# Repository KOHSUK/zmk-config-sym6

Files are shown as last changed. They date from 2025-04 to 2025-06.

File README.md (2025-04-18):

# Symphonie Nr.6 in F-Dur, op. 68, Pastorale

## License & Attribution

The PMW3610 portion of this PCB design is based on “pmw3610_breakout_for_roBa”  
originally created by kumamuk‑git (https://github.com/kumamuk‑git/roBa/tree/main/pcb/pmw3610_breakout_for_roBa).
© kumamuk‑git. Licensed under GNU General Public License v3.0 (GPL‑3.0).

This modified design (files under `pcb`) is also distributed under GPL‑3.0.  
Corresponding source (KiCad project) is available at:  
https://github.com/KOHSUK/zmk-config-sym6/tree/main/pcb/assemble_right/

See LICENSE (GPL‑3.0) for full terms.

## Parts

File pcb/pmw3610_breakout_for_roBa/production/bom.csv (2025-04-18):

Designator | Footprint | Quantity | Value | LCSC Part #
C1 | 0603 | 1 | 1u | C14663
C2 | 0603 | 1 | 1u | C15849
C3, C8 | 0603 | 2 | 100n | C19666
C4 | 0603 | 1 | 10n | C19666
C5 | 0603 | 1 | 100n (X7R) | C19666
C6 | 0603 | 1 | 10u (X7R) | C19666
C7 | 0603 | 1 | 10n (X7R) | C19666
C9 | 0603 | 1 | 3.3u/25V | C19666
J1 | pmw3610_connector_b | 1 | Conn_01x08
R1 | 0603 | 1 | 2M
U1 | SOT-23 | 1 | MCP1700T-1802E/TT
U2 | PMW3610DM-SUDU 16Pin | 1 | PMW3610

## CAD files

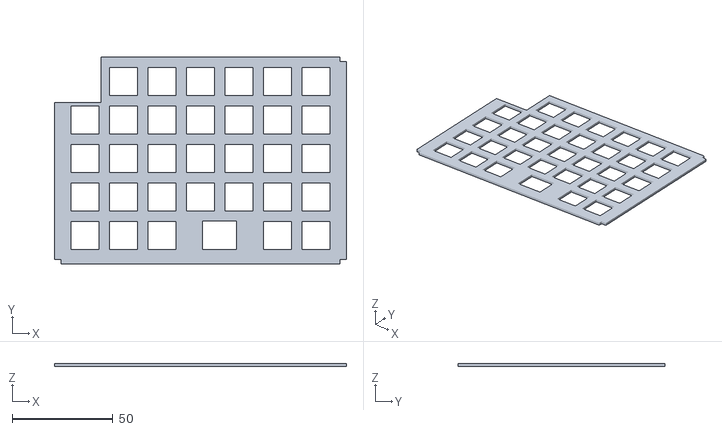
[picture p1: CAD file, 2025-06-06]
models/left_v3/top-plate-l.stl
144.7 x 102.7 x 1.60

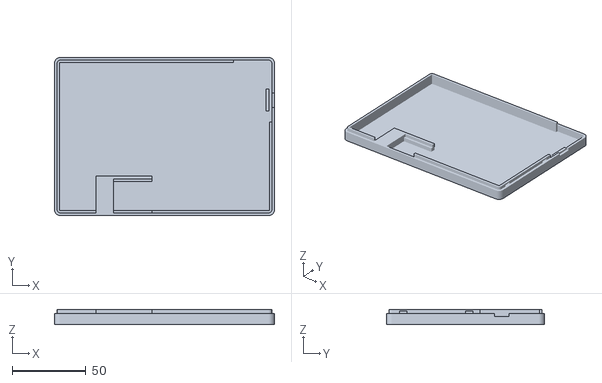
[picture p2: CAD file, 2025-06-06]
models/right_v3/bottom-case-r.stl
149.3 x 107.3 x 9.90

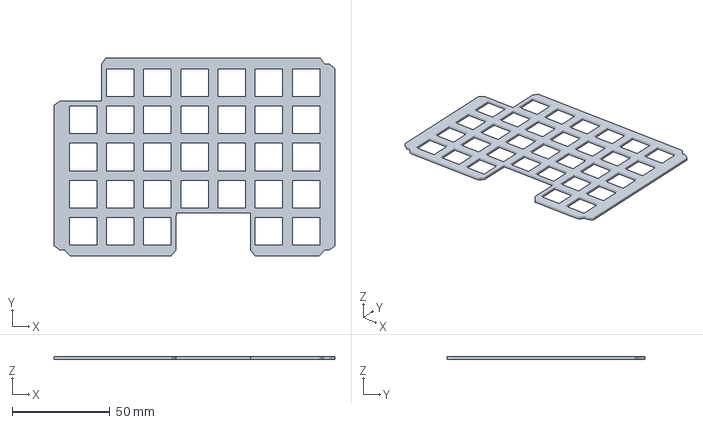
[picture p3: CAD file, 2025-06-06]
models/top_left/top-left.3mf
144.0 x 101.2 x 1.60 mm

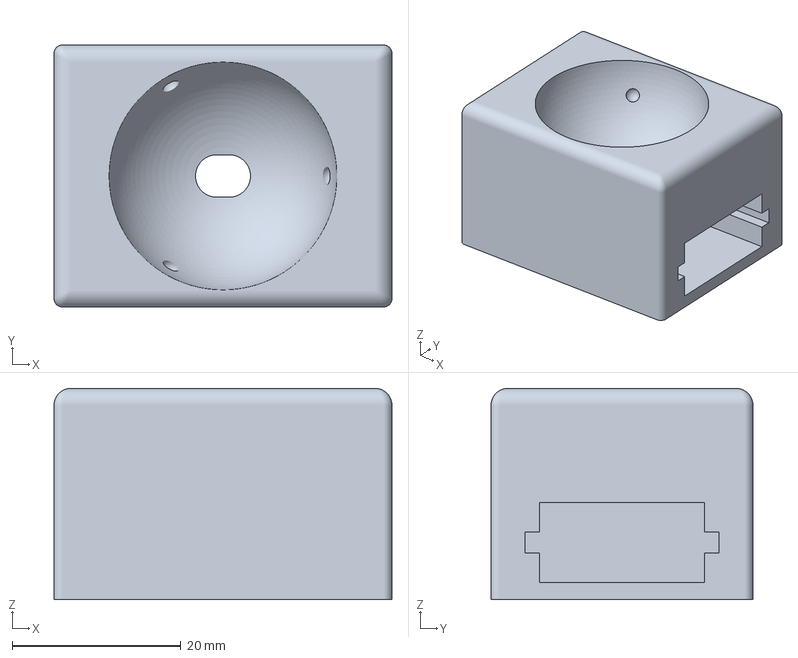
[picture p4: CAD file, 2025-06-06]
models/trackball/trackball-case-v1.3mf
40.0 x 31.0 x 25.0 mm

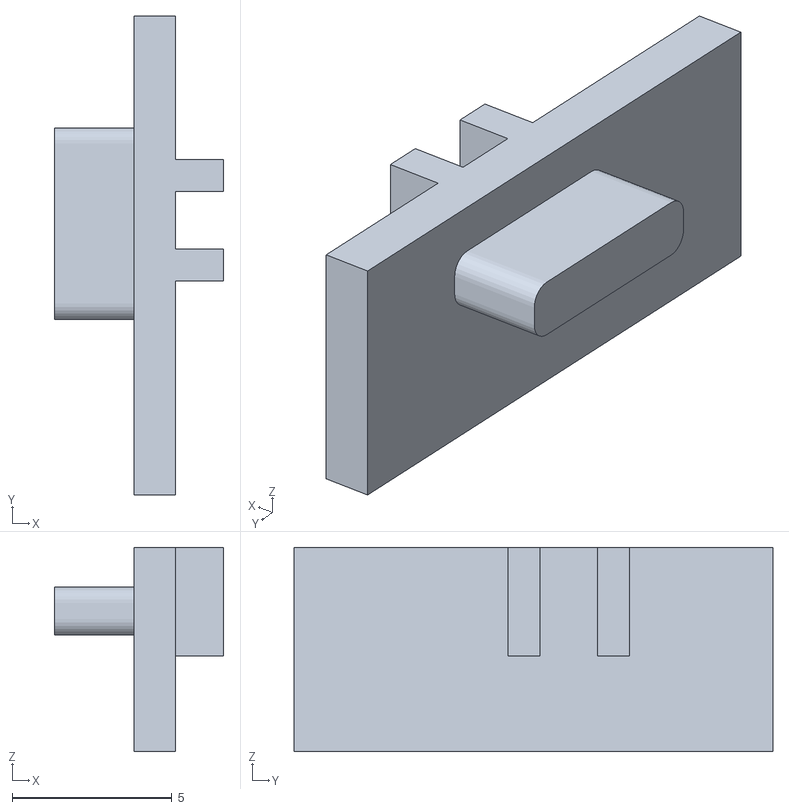
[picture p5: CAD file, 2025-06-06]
models/left_v3/switch.stl
5.30 x 15.0 x 6.40

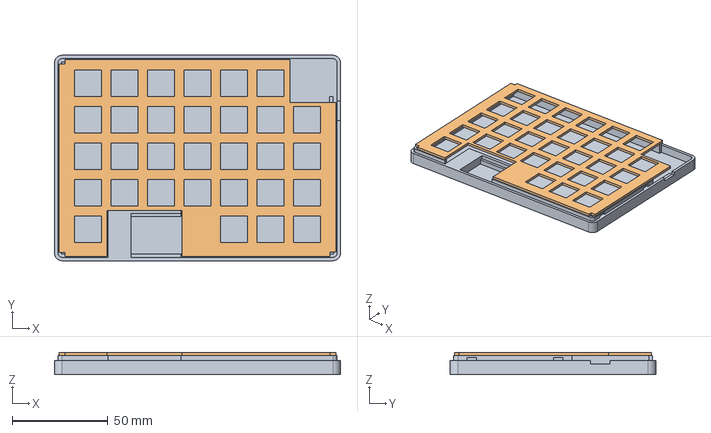
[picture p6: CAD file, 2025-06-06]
models/right_v3/right_v3.FCStd
149.3 x 107.3 x 11.5 mm
BottomCase
TopPlate

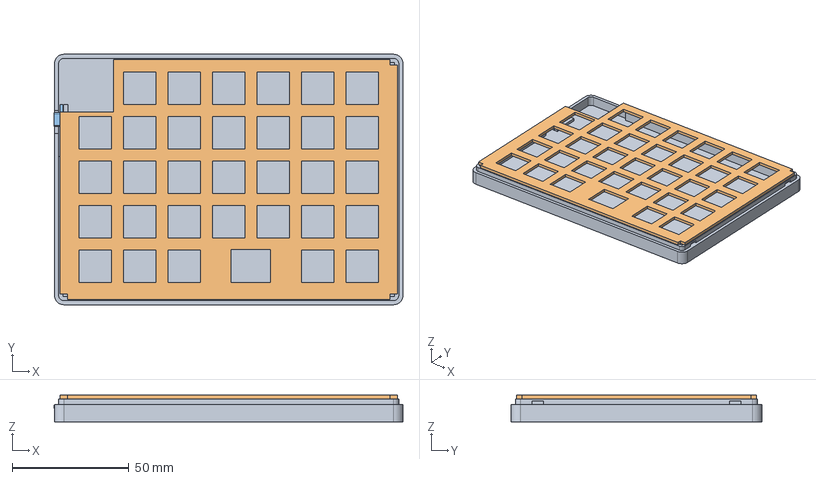
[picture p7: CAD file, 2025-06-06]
models/left_v3/left_v3.FCStd
149.5 x 107.3 x 11.5 mm
BottomCase
TopPlate
Switch

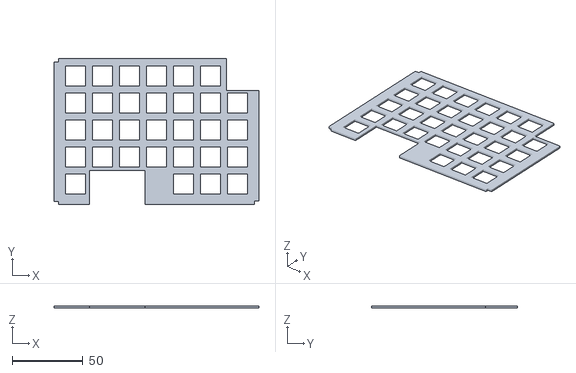
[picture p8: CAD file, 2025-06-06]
models/right_v3/top-plate-r.stl
144.7 x 102.7 x 1.60

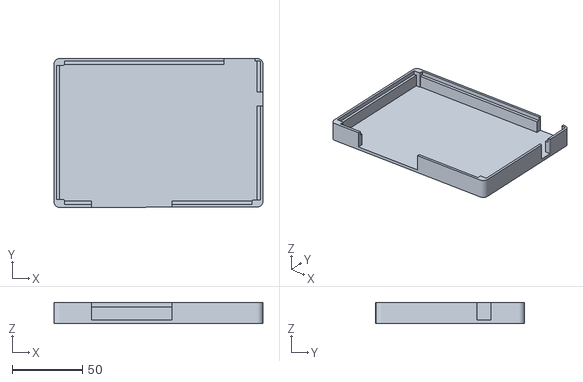
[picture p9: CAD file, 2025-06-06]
models/top_right/bottom-right.stl
149.3 x 106.4 x 15.0

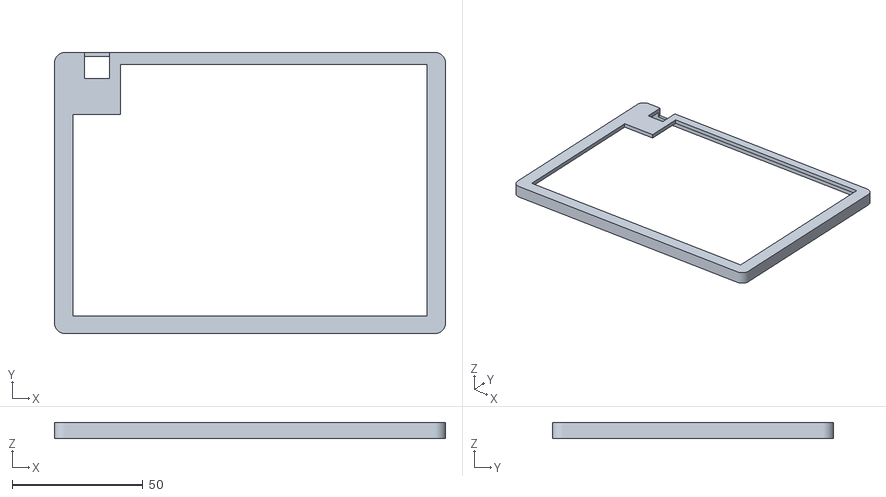
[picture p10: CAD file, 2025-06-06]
models/left_v3/top-cover-l.stl
149.3 x 107.3 x 6.20

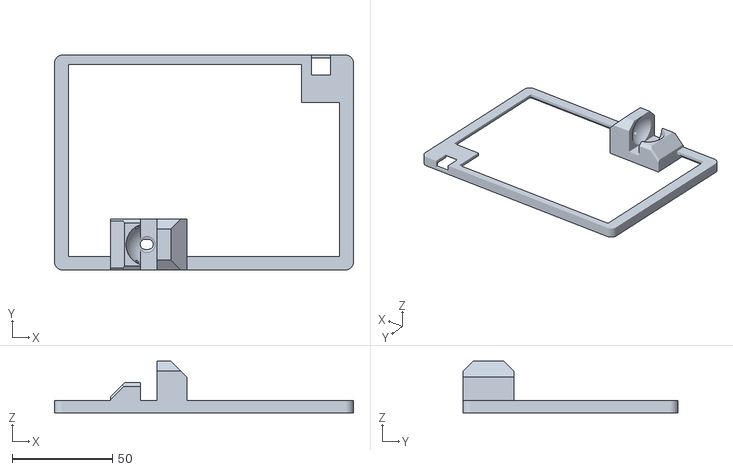
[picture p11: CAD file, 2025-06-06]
models/right_v3/top-cover-r.stl
149.3 x 107.3 x 25.9

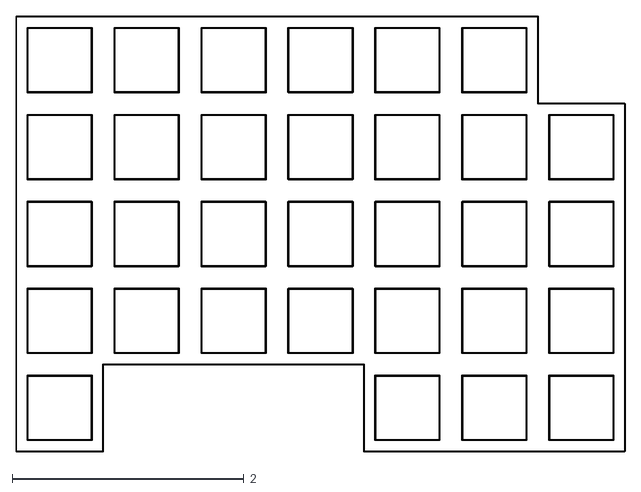
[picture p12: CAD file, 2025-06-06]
models/right_v3/symphonie6_right-Edge_Cuts.dxf
5.25 x 3.75

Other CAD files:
models/top_right/keybaord.step
models/top_left/keybaord.step
models/top_right/top_right.3mf
models/left_v3/bottom-case-l.stl
models/top_right/top_right_small.stl
models/left_v1/bottom-left.3mf
models/left_v1/left_v1.FCStd
models/left_v2/bottom-case-l-v2.3mf
models/left_v2/bottom-case-l-v2.stl
models/left_v2/left_v2.FCStd
models/left_v2/top-cover-l-v2.stl
models/right_v1/right.3mf
models/right_v1/right_v1.FCStd
models/right_v1/top-plate-kicad/symphonie6_right-Edge_Cuts.dxf
models/right_v1/top-right.stl
models/right_v1/trackball-case-v1.3mf
models/right_v1/trackball-case-v1.stl
models/right_v2/bottom-case-r-v2.3mf
models/right_v2/bottom-case-r-v2.stl
models/right_v2/right.3mf
models/right_v2/right.FCStd
models/right_v2/right_v2.FCStd
models/right_v2/switch.stl
models/right_v2/top-cover-r-v2.3mf
models/right_v2/top-cover-r-v2.stl
models/right_v2/top-covor-r-v2.3mf
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

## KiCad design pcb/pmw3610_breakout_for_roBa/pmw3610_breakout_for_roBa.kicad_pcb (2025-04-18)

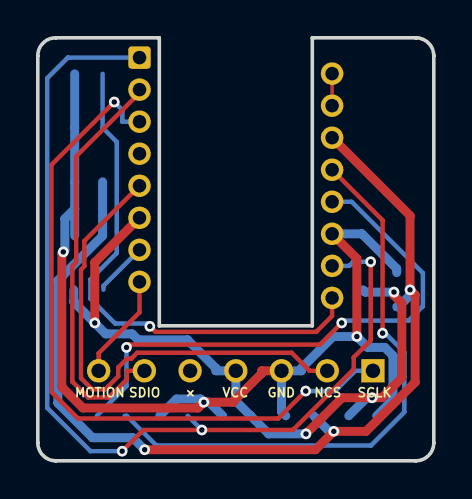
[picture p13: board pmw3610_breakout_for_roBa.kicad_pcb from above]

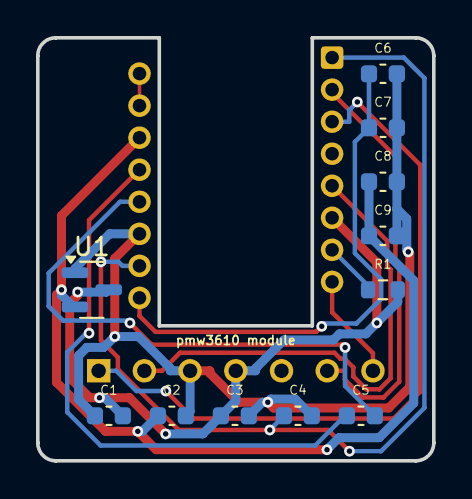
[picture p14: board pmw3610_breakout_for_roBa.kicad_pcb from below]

Board: 2 copper layers, 22.0 x 23.5 mm, 13 parts (11 on the bottom side), 13 nets.

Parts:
C1, C2: 1u; C_0603_1608Metric
C3, C8: 100n; C_0603_1608Metric
C4: 10n; C_0603_1608Metric
C5: 100n (X7R); C_0603_1608Metric
C6: 10u (X7R); C_0603_1608Metric
C7: 10n (X7R); C_0603_1608Metric
C9: 3.3u/25V; C_0603_1608Metric
J1: Conn_01x08; pmw3610_connector_b
R1: 2M; R_0603_1608Metric
U1: MCP1700T-1802E/TT; SOT-23
U2: PMW3610; PMW3610DM-SUDU 16Pin

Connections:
+1V9: C2.1, C8.1, C9.1, U1.2 (VO), U2.14 (VDD)
GND: C1.1, C2.2, C3.2, C4.2, C6.2, C7.2, C8.2, C9.2, J1.3, U1.1 (GND), U2.11 (GND)
MOTION: J1.7 (Pin_6), U2.8 (MOTION)
NCS: J1.2, U2.5 (NCS)
unnamed: C4.1, U2.1 (+VCSEL), U2.10 (PASS_T)
unnamed: U2.15 (XYLASER), U2.16 (-VCSEL)
unnamed: C5.1, U2.13 (CN)
unnamed: C5.2, U2.12 (CP)
unnamed: R1.1, U2.7 (NRESET)
unnamed: C6.1, C7.1, U2.9 (VCP)
SCLK: J1.1, U2.3 (SCLK)
SDIO: J1.6, U2.2 (SDIO)
VCC: C1.2, C3.1, J1.4, R1.2, U1.3 (VI), U2.6 (VDDIO)

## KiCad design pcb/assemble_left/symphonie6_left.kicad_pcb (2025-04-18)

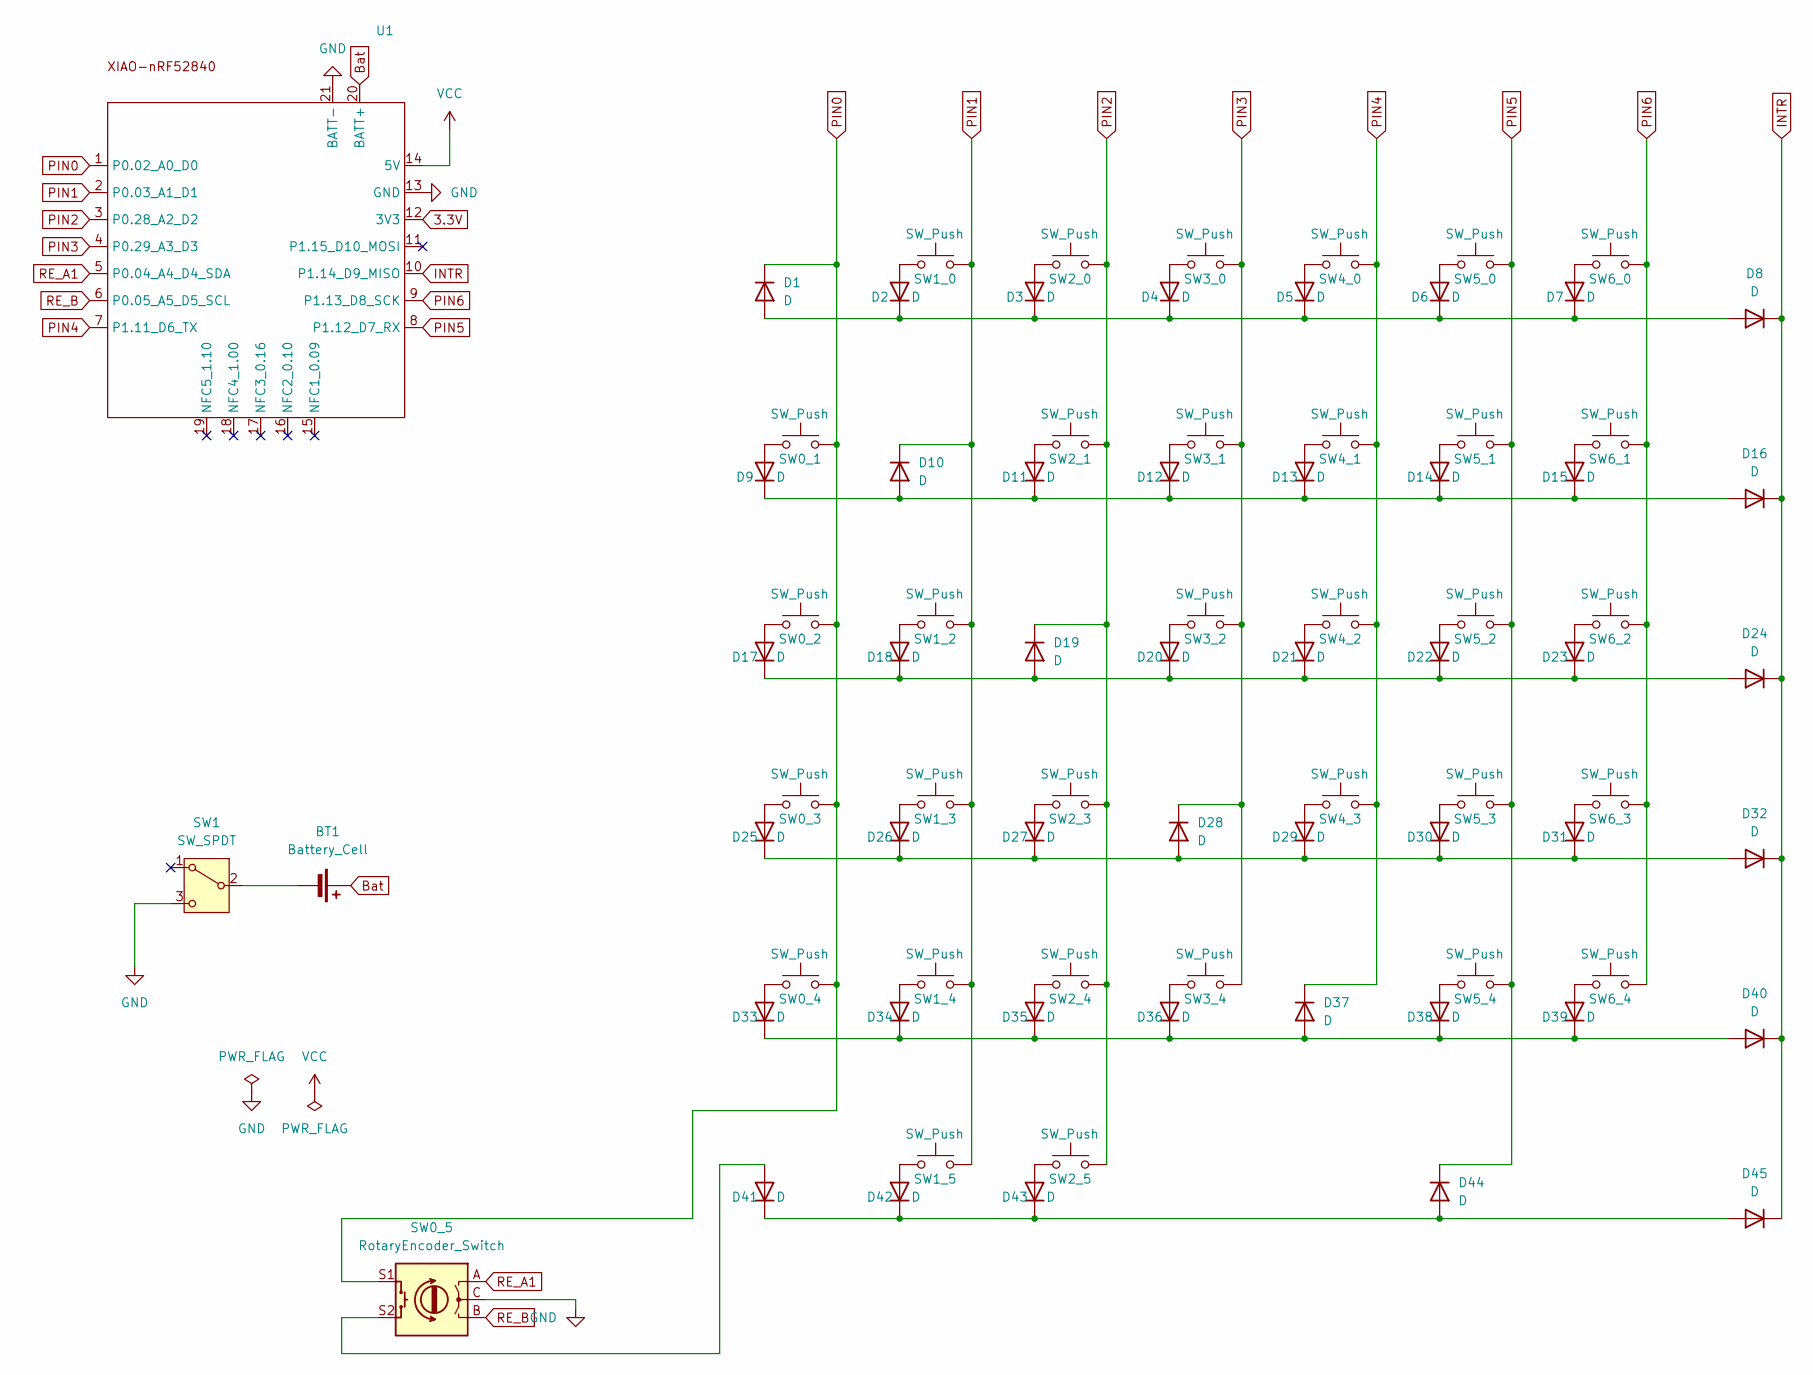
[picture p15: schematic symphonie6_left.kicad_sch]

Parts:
BT1: Battery_Cell; JST_S2B-PH-SM4-TB
D1, D2, D3, D4, D5, D6, D7, D8, D9, D10, D11, D12, D13, D14, D15, D16, D17, D18, D19, D20, D21, D22, D23, D24, D25, D26, D27, D28, D29, D30, D31, D32, D33, D34, D35, D36, D37, D38, D39, D40, D41, D42, D43, D44, D45: D; Diode_TH_SMD
SW0_1, SW0_2, SW0_3, SW0_4, SW1_0, SW1_2, SW1_3, SW1_4, SW1_5, SW2_0, SW2_1, SW2_3, SW2_4, SW2_5, SW3_0, SW3_1, SW3_2, SW3_4, SW4_0, SW4_1, SW4_2, SW4_3, SW5_0, SW5_1, SW5_2, SW5_3, SW5_4, SW6_0, SW6_1, SW6_2, SW6_3, SW6_4: SW_Push; Choc_v2_Hotswap_1u
SW0_5: RotaryEncoder_Switch; RotaryEncoder_Alps_EC11E-Switch_Vertical_H20mm
SW1: SW_SPDT; TGSW_MSK-12D19
U1: XIAO_nRF52840_wBAT_wNFC_1

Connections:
3.3V: U1.12 (3V3)
Bat: BT1.1 (+), U1.20 (BATT+)
GND: SW0_5.C, SW1.3 (C), U1.13 (GND), U1.21 (BATT-)
INTR: D8.1 (K), D16.1 (K), D24.1 (K), D32.1 (K), D40.1 (K), D45.1 (K), U1.10 (P1.14_D9_MISO)
unnamed: BT1.2 (-), SW1.2 (B)
unnamed: D1.2 (A), D2.1 (K), D3.1 (K), D4.1 (K), D5.1 (K), D6.1 (K), D7.1 (K), D8.2 (A)
unnamed: D2.2 (A), SW1_0.1
unnamed: D3.2 (A), SW2_0.1
unnamed: D4.2 (A), SW3_0.1
unnamed: D5.2 (A), SW4_0.1
unnamed: D6.2 (A), SW5_0.1
unnamed: D7.2 (A), SW6_0.1
unnamed: D9.2 (A), SW0_1.1
unnamed: D9.1 (K), D10.2 (A), D11.1 (K), D12.1 (K), D13.1 (K), D14.1 (K), D15.1 (K), D16.2 (A)
unnamed: D11.2 (A), SW2_1.1
unnamed: D12.2 (A), SW3_1.1
unnamed: D13.2 (A), SW4_1.1
unnamed: D14.2 (A), SW5_1.1
unnamed: D15.2 (A), SW6_1.1
unnamed: D17.2 (A), SW0_2.1
unnamed: D17.1 (K), D18.1 (K), D19.2 (A), D20.1 (K), D21.1 (K), D22.1 (K), D23.1 (K), D24.2 (A)
unnamed: D18.2 (A), SW1_2.1
unnamed: D20.2 (A), SW3_2.1
unnamed: D21.2 (A), SW4_2.1
unnamed: D22.2 (A), SW5_2.1
unnamed: D23.2 (A), SW6_2.1
unnamed: D25.2 (A), SW0_3.1
unnamed: D25.1 (K), D26.1 (K), D27.1 (K), D28.2 (A), D29.1 (K), D30.1 (K), D31.1 (K), D32.2 (A)
unnamed: D26.2 (A), SW1_3.1
unnamed: D27.2 (A), SW2_3.1
unnamed: D29.2 (A), SW4_3.1
unnamed: D30.2 (A), SW5_3.1
unnamed: D31.2 (A), SW6_3.1
unnamed: D33.2 (A), SW0_4.1
unnamed: D33.1 (K), D34.1 (K), D35.1 (K), D36.1 (K), D37.2 (A), D38.1 (K), D39.1 (K), D40.2 (A)
unnamed: D34.2 (A), SW1_4.1
unnamed: D35.2 (A), SW2_4.1
unnamed: D36.2 (A), SW3_4.1
unnamed: D38.2 (A), SW5_4.1
unnamed: D39.2 (A), SW6_4.1
unnamed: D41.2 (A), SW0_5.S2
unnamed: D41.1 (K), D42.1 (K), D43.1 (K), D44.2 (A), D45.2 (A)
unnamed: D42.2 (A), SW1_5.1
unnamed: D43.2 (A), SW2_5.1
PIN0: D1.1 (K), SW0_1.2, SW0_2.2, SW0_3.2, SW0_4.2, SW0_5.S1, U1.1 (P0.02_A0_D0)
PIN1: D10.1 (K), SW1_0.2, SW1_2.2, SW1_3.2, SW1_4.2, SW1_5.2, U1.2 (P0.03_A1_D1)
PIN2: D19.1 (K), SW2_0.2, SW2_1.2, SW2_3.2, SW2_4.2, SW2_5.2, U1.3 (P0.28_A2_D2)
PIN3: D28.1 (K), SW3_0.2, SW3_1.2, SW3_2.2, SW3_4.2, U1.4 (P0.29_A3_D3)
PIN4: D37.1 (K), SW4_0.2, SW4_1.2, SW4_2.2, SW4_3.2, U1.7 (P1.11_D6_TX)
PIN5: D44.1 (K), SW5_0.2, SW5_1.2, SW5_2.2, SW5_3.2, SW5_4.2, U1.8 (P1.12_D7_RX)
PIN6: SW6_0.2, SW6_1.2, SW6_2.2, SW6_3.2, SW6_4.2, U1.9 (P1.13_D8_SCK)
RE_A1: SW0_5.A, U1.5 (P0.04_A4_D4_SDA)
RE_B: SW0_5.B, U1.6 (P0.05_A5_D5_SCL)
VCC: U1.14 (5V)

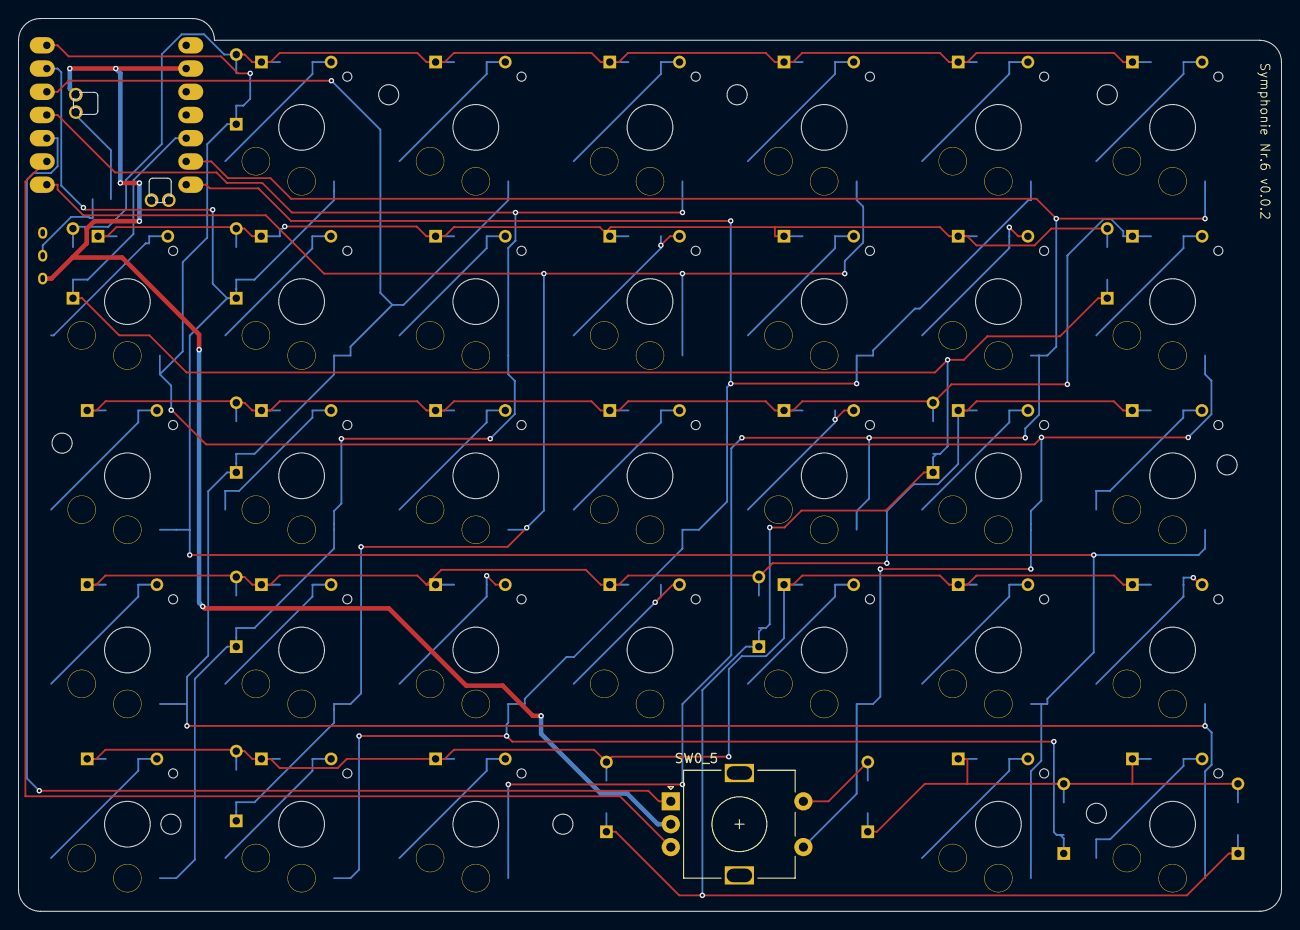
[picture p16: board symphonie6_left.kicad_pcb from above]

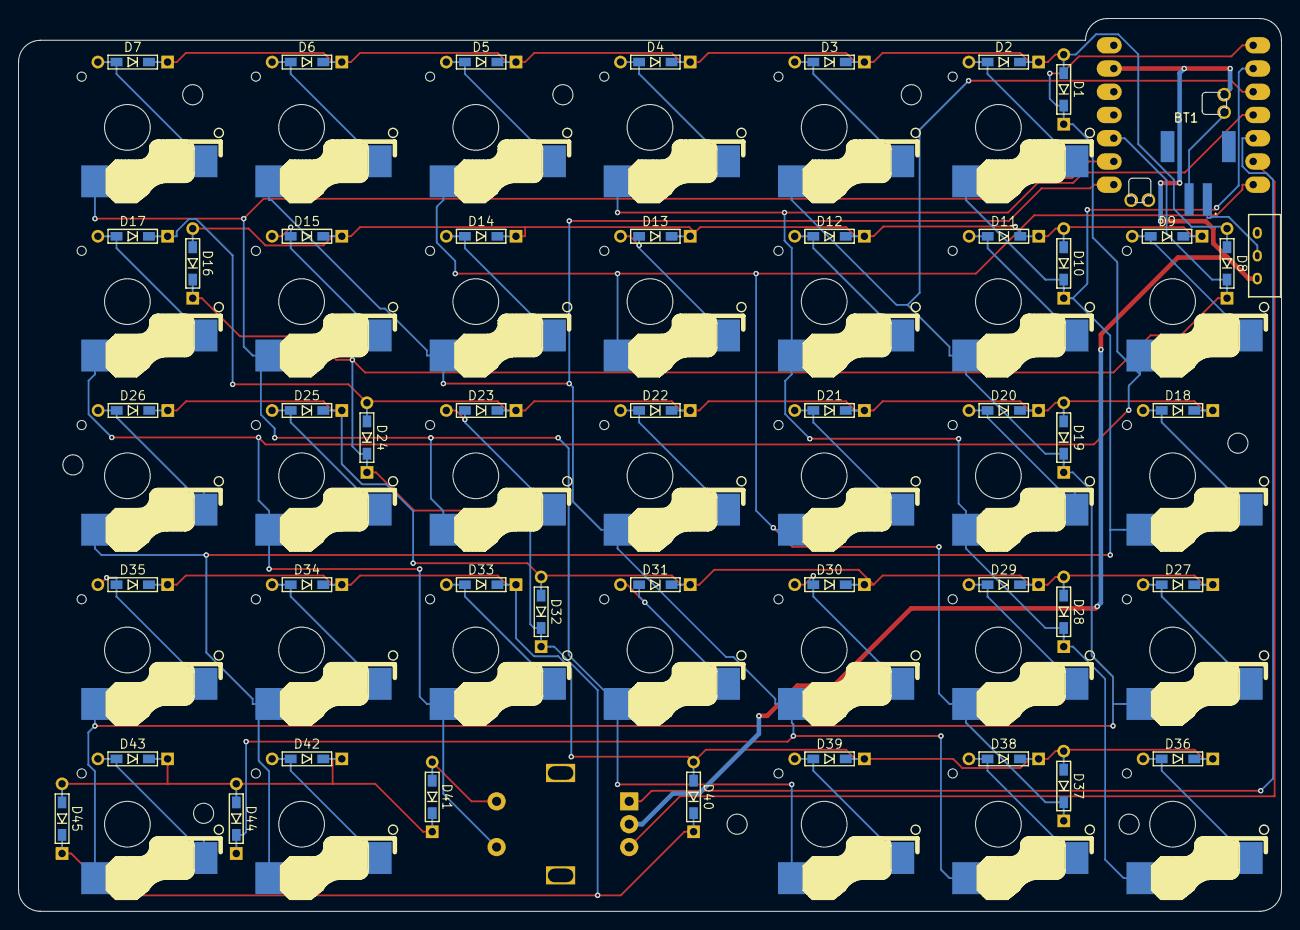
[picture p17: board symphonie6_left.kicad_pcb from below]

Board: 2 copper layers, 138.1 x 97.6 mm, 89 parts (2 on the bottom side), 52 nets.

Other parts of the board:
Ref**: Val**; m2_Screw_Hole
Ref**#2, Ref**#3, Ref**#4, Ref**#5, Ref**#6, Ref**#7, Ref**#8: Val**; m2_Screw_Hole

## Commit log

2025-03-20 Add board and shield configurations for Seeeduino Xiao BLE in build.yaml
2025-03-20 Add ZMK Studio configuration to Symphonie Nr.6 left board file
2025-03-21 Refactor Symphonie Nr.6 overlays: update GPIO configurations to include pull-down resistors
2025-03-21 Revert "Refactor Symphonie Nr.6 overlays: update GPIO configurations to include pull-down resistors"
    This reverts commit b9ea86eca23de07c471f807520becbd8ab0391f2.
2025-04-18 v0.0.2 pcb
    [bom.csv, designators.csv, pmw3610_breakout_for_roBa.kicad_pcb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]
2025-04-18 Refactor Symphonie Nr.6 configuration: update GPIO settings and PMW3610 driver integration of the right side
2025-04-20 Refactor Symphonie Nr.6: update keymap bindings and GPIO configuration for left encoder
2025-04-28 Refactor Symphonie Nr.6 configuration: enable automouse and scroll layers in overlay, add battery reporting settings in right config
2025-06-06 feat: added several 3D models
    [bottom-case-l-v2.3mf, bottom-case-l-v2.stl, bottom-case-l.stl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]
